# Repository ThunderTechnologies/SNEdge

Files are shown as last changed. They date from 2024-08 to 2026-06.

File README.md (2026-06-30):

# SNEdge - An Opensource SNES Edge Sharpener
**This has only been tested on a few SNES revisions | Proceed with caution**

SNEdge V2 is to a state where it can be considered stable. As SNES revisions are tested, instructions will be added to the wiki.
For now, only the full bypass is supported. The sidecar install will get a dedicated design at some point.

The SNEdge corrects much of the smearing that's present on the 2 chip SNES. It taps the console's RGB, cleanly buffers it, and applies a tuned amount of sharpening to bring back the crisp edges the stock 2 chip output loses.

This is the latest revision of the SNEdge. Over the original it refines the input biasing, properly impedance-matches the outputs to the 75Ω video standard, and re-tunes the sharpening — see [How It Works](#how-it-works) for the details. It still uses 0805 components, so it's relatively approachable to solder by hand.

The SNEdge pairs with the **Multiout QSB**, which makes for a clean install right at the multiout. There are two ways to connect the SNEdge to the QSB:

- **U.FL Coax (recommended)** — connect the two boards with U.FL-terminated 1.13mm coax (the same cable sold as WiFi antenna pigtails). This is the preferred method for new installs: it's a higher-quality, shielded connection, the U.FL connectors let you position and route the cable freely, and the cable is cheaper and easier to source than FFC. Around 10cm length works well.
- **FFC cable** — a single ribbon cable between the two boards. Still supported, but coax is the better choice going forward.

> Where to get the boards:<br />
[SNEdge V2 Gerbers](https://github.com/ThunderTechnologies/SNEdge/tree/SNEdge_V2/SNEdge%20PCB/Manufacturing)<br />
[FFC QSB Gerbers](https://github.com/ThunderTechnologies/SNEdge/tree/SNEdge_V2/Multi%20AV%20QSB/FFC%20QSB/Manufacturing)<br />
[Coax QSB Gerbers](https://github.com/ThunderTechnologies/SNEdge/tree/SNEdge_V2/Multi%20AV%20QSB/U.FL%20QSB/Manufacturing)<br />
Note:  The coax is standard U.FL 1.13mm WiFi antenna pigtail cable (roughly 10cm), widely available online.<br />

The SNEdge

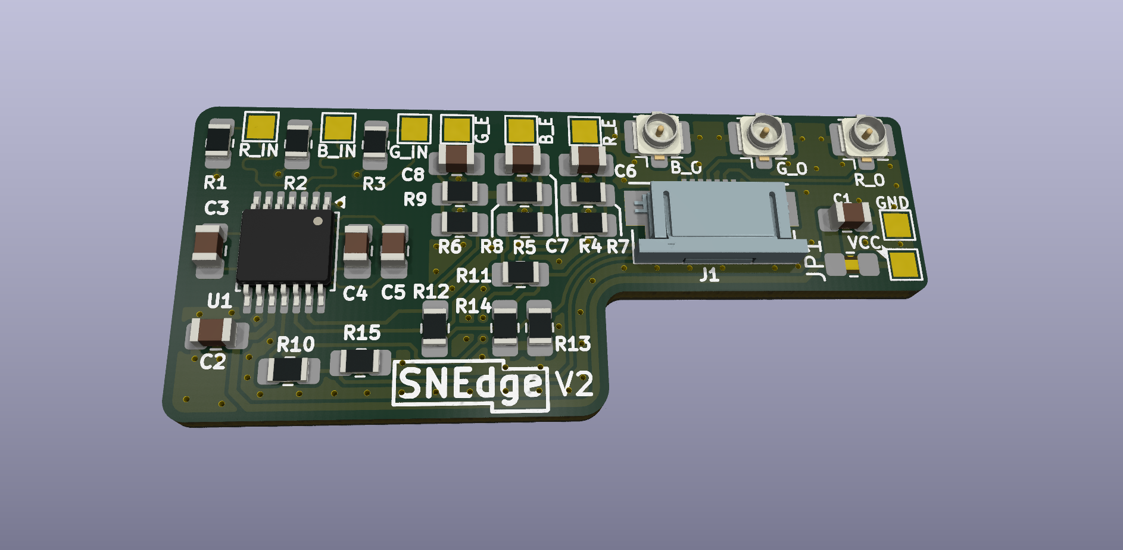
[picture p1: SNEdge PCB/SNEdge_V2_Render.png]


The Multiout U.FL QSB

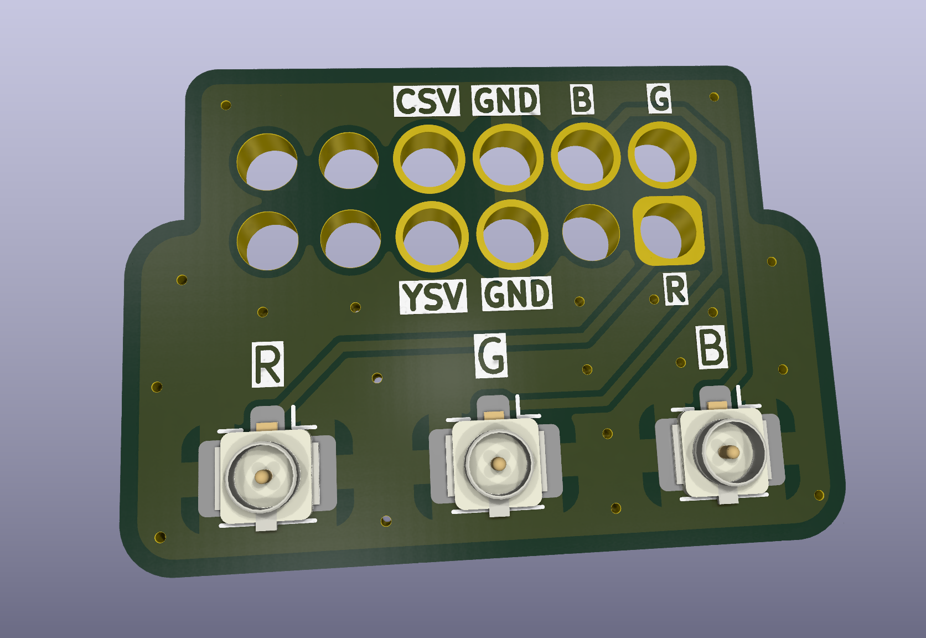
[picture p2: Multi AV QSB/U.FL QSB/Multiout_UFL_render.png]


The Multiout FFC QSB

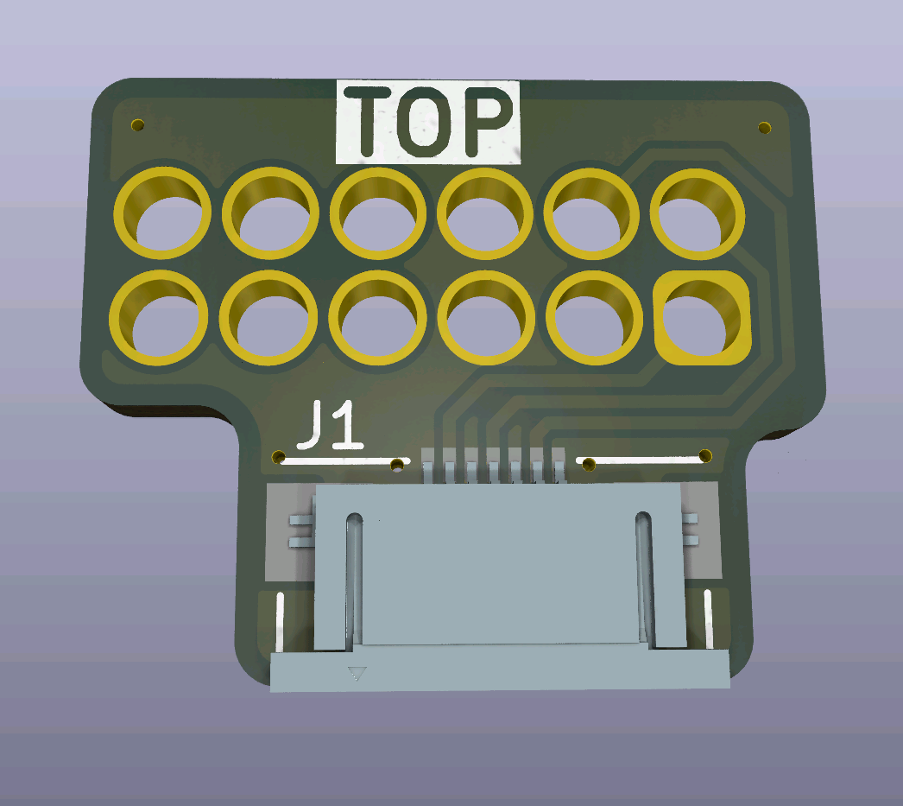
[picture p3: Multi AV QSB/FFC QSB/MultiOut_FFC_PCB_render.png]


(I'll be adding screenshots of the video output soon)

## How It Works

The SNEdge taps the RGB video signal at the PPU2 output (the Q3/Q5/Q7 points) and runs each channel through a THS7376 video amplifier. The 2 chip SNES PPU has slow color transitions that show up on screen as smearing; cleanly buffering the signal and applying a small amount of high-frequency peaking sharpens those transitions without changing the rest of the picture.

A few design choices worth knowing about:

- **Ground reference and input attenuation.** Each RGB input has a 7.5kΩ pull-down resistor. It does two jobs. First, it gives the amplifier input a proper, defined ground/DC reference so the signal sits where it should. Second, it attenuates the input down to around 2.20Vptp, which keeps the signal within the THS7376's 2.35Vptp linear input voltage spec and so avoids clipping the amplifier's input. For context, the SNES's original RGB amp has an input impedance of about 12kΩ.
- **Sharpening.** A small feedback capacitor on each channel provides the edge sharpening. It's tuned for the most sharpening you can get before overshoot starts to become visible.
- **75Ω output.** Each output uses a 240Ω / 110Ω network. The thevenin equivalent is about 75Ω, which is the standard video source impedance, so the SNEdge drives a cable correctly.
- **Optional noise caps.** Adding a 10uF cap to each of C90-C94 on the SNES motherboard helps suppress video noise. These are optional — you can leave them out and only add them if you notice any noticeable noise in the output.

## Installation
I don't have specific, picture instructions on how to install the SNEdge yet (These will be slowly added to the wiki).

However, looking at the [SNES schematic (PDF)](https://wiki.superfamicom.org/uploads/snes_schematic_color.pdf) from [wiki.superfamicom.org](wiki.superfamicom.org) will be critical for understanding how to install this.

This revision installs using the **RGB Bypass** method, which gives the best sharpness. The older **Sidecar** method (which didn't require desoldering any components) is no longer supported on this revision — see [A Note on the Sidecar Install](#a-note-on-the-sidecar-install) below if that's what you're after.

Optionally, you can solder an additional 10uF capacitor onto C90, C91, C92, C93, and C94 on the SNES motherboard (for PAL systems, it's C91, C92, C93, C94, and C95). These help reduce video noise. They aren't required, but if you notice any noticeable noise in the output, adding them should clean it up.

Below is an SOT-23 pinout I will be referencing later.
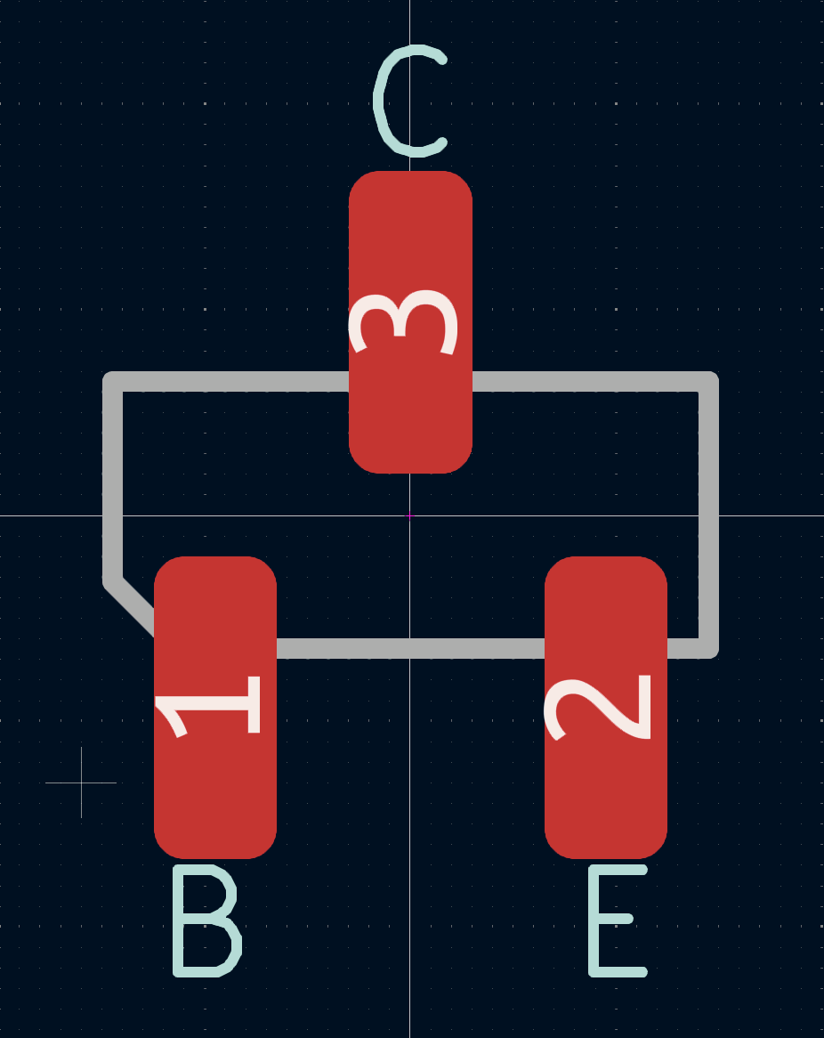
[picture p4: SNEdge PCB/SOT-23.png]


### A Note on the Sidecar Install
The Sidecar method is **not supported on this revision.** If you want a sidecar-style install, the original SNEdge can still be used for that. A dedicated sidecar revision may be released later by ThunderTechnologies.

This revision has not been tested in a sidecar configuration. It may work fine, but it's untested, so it isn't documented as a supported install here. For this revision, use the Full RGB Bypass install below.

### Full RGB Bypass Install
(Please note that PAL system installation is a bit different, I have info on this, and will be adding it eventually.)

Mount the SNEdge, keeping one priority above everything else: **keep the input wires as short as possible.**

The R, G, and B input wires are very sensitive to parasitic capacitance, so position the SNEdge so those wires reach their mainboard points (Q3, Q5, Q7) over the shortest distance you can manage. Keeping the input wires as close to the mainboard points as possible is the single most important part of placement. It's also preferred to keep the three input wires at **similar lengths** to each other.

Orientation depends on how you're connecting to the QSB:

- **Coax (recommended):** the U.FL coax gives you a lot of freedom. Orient and place the SNEdge however best keeps the input wires short, and route the coax wherever is convenient.
- **FFC:** point the FFC connector toward the multiout of the SNES.

Remove Q3, Q5, and Q7. If you only care about RGB working, remove R8, R9, R13, R14, R18, and R19. If you also care about Composite video and S-Video, also remove C6, C7, and C8.

Q3 is Red, Q5 is Green, and Q7 is Blue. Looking at the SOT-23 pinout above, pin 3 of each is ground. Pin 1 of each is the R, G, and B signals that will be soldered to the SNEdge.

Solder leads from Q3 to R_IN and GND.

Solder leads from Q5 to G_IN and GND.

Solder leads from Q7 to B_IN and GND.

The SNEdge needs to output video to U7 (S-ENC) on the SNES in order for composite video and S-video.

The SNEdge R_E, G_E, and B_E outputs go to U7's pins 20, 21, 22 respectively. (you can ignore the GND pin next to these if you'd like. If you care, connect it to pin 2 of U7.

Solder the multiout QSB on to the bottom of the SNES where the multiout pins are. If you're looking at the bottom of the SNES board, the "TOP" label on the QSB needs to be facing you. (If you're using FFC, also orient it so the FFC connector points toward the SNEdge; with coax, routing is flexible so this doesn't matter.)

The SNEdge needs 5V. Solder 5V to the + and ground to the -

Connect the SNEdge to the QSB. Coax is the recommended method:

- **Coax (recommended):** connect the SNEdge to the QSB with U.FL-terminated 1.13mm coax (the cable commonly sold as WiFi antenna pigtails). Around 10cm length works well. It's the better-quality connection, easy to route thanks to the U.FL connectors, and cheap to source.
- **FFC cable:** alternatively, connect an FFC cable between the SNEdge and the QSB. The contacts of the FFC face down, with the blue tabs facing up.

Congrats! You have completed the full RGB bypass install. Enjoy some crispy RGB.

### A Note on PAL Systems
**PAL has not been tested yet.** The SNEdge should work on PAL consoles since they share the same PPU, but please treat PAL installs as experimental for now.

The main difference to be aware of is the cap designators: if you add the optional noise-reduction caps, on PAL systems they go on **C91, C92, C93, C94, and C95** instead of C90-C94. PAL boards also differ around the encoder, so the Full RGB Bypass encoder connections (the U7 pin references above) may not match a PAL console one-to-one. Until PAL-specific details are confirmed and documented, treat a PAL install as experimental and proceed carefully. More complete PAL instructions will be added as they're verified.

### Credits

The SNEdge is based on the work of YoshiYukiBlade over on the [shmups.system11.org](https://shmups.system11.org/viewtopic.php?t=70196) forums.<br />
V2 was made possible by the many contributions from [RetroLoom](https://github.com/RetroLoom)

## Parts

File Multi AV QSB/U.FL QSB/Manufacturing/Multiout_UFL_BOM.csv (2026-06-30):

Reference | Value | Qty | Digi_PN | MFG_PN
J2 | R | 1 | H11891CT-ND | U.FL-R-SMT-1(10)
J3 | G | 1 | H11891CT-ND | U.FL-R-SMT-1(10)
J4 | B | 1 | H11891CT-ND | U.FL-R-SMT-1(10)

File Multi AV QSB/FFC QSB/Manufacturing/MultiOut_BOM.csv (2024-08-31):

Item | Qty | Reference(s) | Value | Digi_PN | MFG_PN | Type
1 | 1 | J1 | RGB_OUT | WM8933CT-ND | 527460771 | SMD

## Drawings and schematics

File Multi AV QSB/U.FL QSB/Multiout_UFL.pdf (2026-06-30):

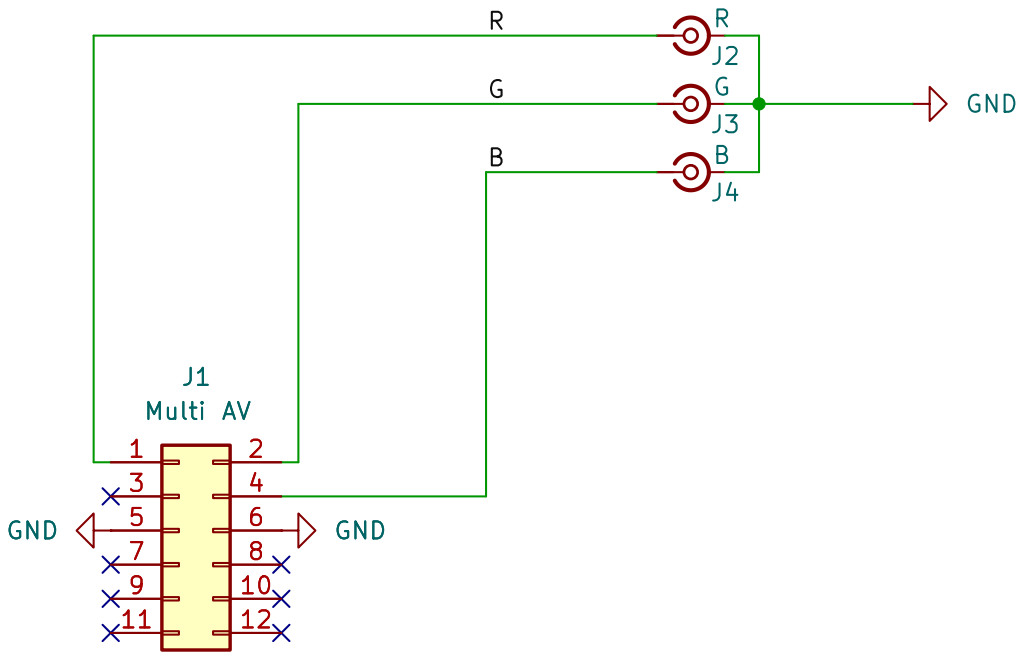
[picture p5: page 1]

Design by Daniel Arnold (RetroLoom)
Innov8bit
Sheet: /
File: Multiout_UFL.kicad_sch
Title: MultOut QSB

Size: A4 | Rev: 1
KiCad E.D.A. 10.0.3 | Id: 1/1

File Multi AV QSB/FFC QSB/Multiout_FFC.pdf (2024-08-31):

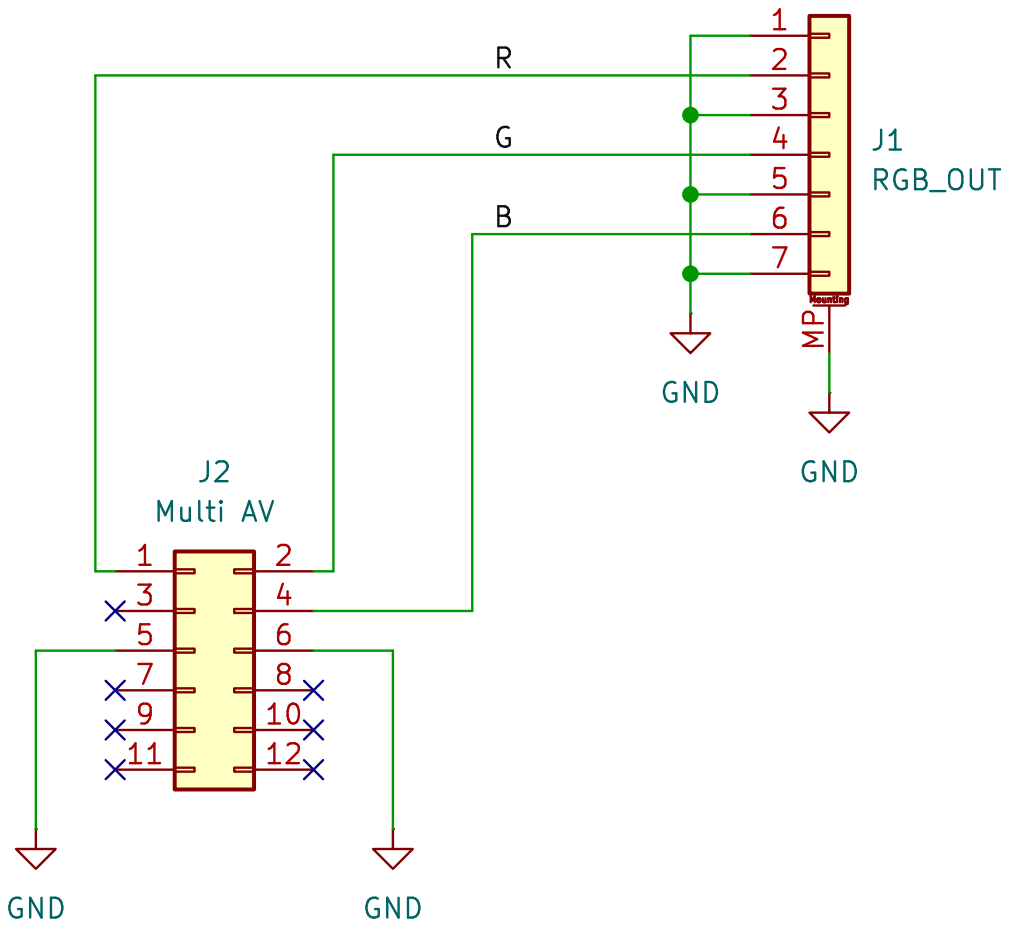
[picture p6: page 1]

File: MultiOut.kicad_sch Sheet: / ThunderTechnologies

Id: 1/1 Title: MultOut QSB

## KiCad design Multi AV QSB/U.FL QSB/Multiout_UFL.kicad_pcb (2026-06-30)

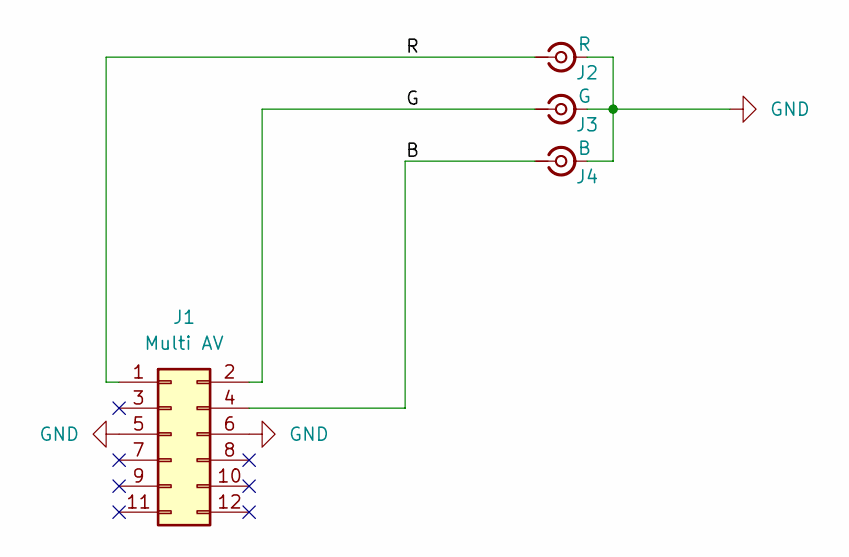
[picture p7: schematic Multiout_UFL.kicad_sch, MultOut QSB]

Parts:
J1: Multi AV; Multi_AV_QSB
J2: R; U.FL_Hirose_U.FL-R-SMT-1_Vertical; MFG_PN U.FL-R-SMT-1(10); Digi_PN H11891CT-ND
J3: G; U.FL_Hirose_U.FL-R-SMT-1_Vertical; MFG_PN U.FL-R-SMT-1(10); Digi_PN H11891CT-ND
J4: B; U.FL_Hirose_U.FL-R-SMT-1_Vertical; MFG_PN U.FL-R-SMT-1(10); Digi_PN H11891CT-ND

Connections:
/B: J1.4, J4.1 (In)
/G: J1.2, J3.1 (In)
/R: J1.1, J2.1 (In)
GND: J1.5, J1.6, J2.2 (Ext), J3.2 (Ext), J4.2 (Ext)

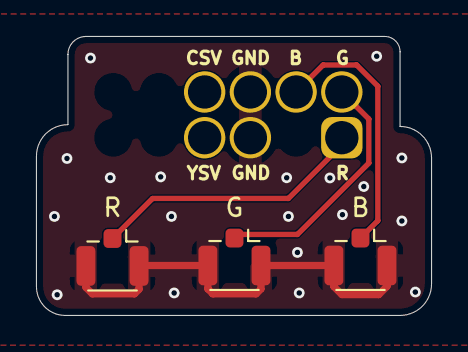
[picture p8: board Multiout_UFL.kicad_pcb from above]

Board: 2 copper layers, 21.9 x 15.5 mm, 4 parts (0 on the bottom side), 4 nets.

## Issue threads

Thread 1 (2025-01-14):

Flex Lenght

Radeon91, 2025-01-14:
hello, what distance should we use for the fex? would a 10cm be ok?

ThunderTechnologies, 2025-01-14:
10cm is what I used. Specifically, I used this part: [https://www.digikey.com/en/products/detail/molex/0150200751/2972673](https://www.digikey.com/en/products/detail/molex/0150200751/2972673)

Looks like I forgot to mention this part anywhere. I'll add this to the BOM of the SNEDGE.

Radeon91, 2025-01-15:
Great, thanks.

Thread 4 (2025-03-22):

Sidecar Install GPM-02 Vertical Bars

RetroLoom, 2025-03-22:
First I want to say thank you for your work on this implementation. Overall it was easy to install as a sidecar and I am pretty impressed with the results.

On my GPM-02 it does seem to bring out some vertical bars and a strange noise that is not present before the mod. I don't think this is unique to the SNEdge because I have seem nearly identical artifacts from using the Buttersoft / Torapu filter and its renditions on the GPM-02 as well. I spent a bit of time trying looking for ways to reduce or eliminate the lines but so far nothing has worked. I have done the usual upgrades to C90-C95 caps, and also have an upgraded voltage regulator. I tried upping C7 on the SNEdge to a 10uf which showed no change. I also tried different ground points which seemed to change / make the noise worse but I was never able to improve it. PPU2 pins 3 and 27 have been removed from the circuit by removing their series resistors which did seem to have with some of the vertical bars.

I think I am going to move on to the full bypass install and see how my results are with that, but I thought I would test and try what I could while I had it configured as a side car and report it.

RetroLoom, 2025-03-22:
I just finished the full bypass install without connecting U7 and thought I would make a quick report. 90-95% of the noise and vertical bars are no gone and everything looks very nice and stable. There is still a faint amount of vertical bars so not quite 100%. I will try to do a bit more research and attempt to get some decent captures. I will also move on to an RGB-02 revision I have at some point which didn't seem to suffer from these same artifacts when using the Buttersoft / Torapu mod after removing PPU2 pins 3 and 27 from the circuit. I will report back when I get around to this.

RetroLoom, 2025-03-22:
I repositioned the side car and shortened my wires as much as possible / practical and this seems to have eliminated all of the vertical line noise that was happening on the full bypass install. It seemed in my testing that most of this noise was caused by the extra inductance on the ground wires. I am not sure how much this would have helped with the sidecar only install because it was very prominent there. But this can be emphasized for anyone else installing this mod.

ThunderTechnologies, 2025-06-03:
Thank you for your input and testing (and my apologies for taking forever to respond). I'll be sure to mention ground wire length in the readme here soon.

leonkiriliuk, 2025-07-21:
I've been experimenting with the SNEdge on a Japanese GPM-02 and wanted to provide my feedback here. I did a full RGB bypass install with the 10uF caps added. I kept the wires as short as possible.

- SNES noise differs between SNES revisions. No single solution will fix all SNES systems. This is why other commercial products have multiple adapters, depending on what system you have.
- If your display device is a CRT (composite, SVideo) or RGB CRT (PVM) then the solution is pretty much perfect. I can't tell the difference between a SNEdge modded system and my 1chip on my PVM! Before I easily could. The SNEdge gets rid of the horizontal smear that the SNES suffers from.
- If your display device is an LCD, you're at the mercy of your scalar and more work is needed to get it to 1chip quality on some SNES systems.
- Some SNES systems (like the GPM-02) have high frequency noise in the video signal. The original RGB path did a good job at hiding this noise by smearing it away. When you get rid of the smear, your scalar does a good job at making the existing noise visible.
- Other solutions show the vertical jailbars as well. Voultar's wiki shows it in his screen captures of the GPM-02 basic install. RetroSix talks about it in his Wiki (he believes it to be DRAM noise)
- Some of the solutions discussed here (like adding 15pF caps on the input) remove some of this noise by simply introducing some of the smear back. They don't tackle the original source of the noise. I played with different values for these caps; the higher the value, the higher the horizontal smear comes back.
- OSSC Pro in scalar mode, with the built-in SNES profile, does the exact same thing. It removes the vertical jailbars by introducing a small amount of horizontal smear. In pure or adaptive line multiplier, the vertical bars are perfectly visible, but the image is also perfectly sharp.
- Swapping a THS7374 for the THS7376 showed no difference. I believe you can use both.
- Enabling the built-in filter of the TI video amps turns on their internal input filters which generates a lot of smear. I'm guessing it's equivalent to adding 100pF caps on the input.

On the GPM-02 I've done other experiments:
- adding SVideo / component output with the full RGB bypass doesn't impact RGB output image quality
- the 3 ground wires for RGB inputs don't make a difference if they're there or not
- lifting the S-PPU2 RGB pins (95,96,97) and running dedicated wires directly to the SNEdge made no difference

leonkiriliuk, 2025-07-21:
SNES is noisy by nature (Even 1chip) Turn off LPF on an SNES 1CHIP RGB amp, feed it into OSSC and you'll see the noise in solid black screen.  The THS7374 LPF does a good job at removing it. The GSCARTSW uses the same chip and has it on by default which is why people turn off the LPF on the RGB amp (too many LPFs tend to blur the image a bit)

The SNEdge output has no LPF at all (pin 9 is held at Vcc = LPF off) So now you let all the noise through while trying to remove it.

As for ground; if you look at the PCB, you'll see all the grounds connect to the same ground plain. There's such a thing as too many grounds; N64 suffers from this - too many grounds can introduce ground loops / noise.

I'll try and get other SNES models and play around. I think the design GPM-02 has inherit high frequency noise in the video output. It needs to be identified and removed. I hope other revisions have less.

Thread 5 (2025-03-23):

RGB Pins Shorted to Ground?

SnoopKatt, 2025-03-23:
I did the install and am running into something odd. I did the full bypass and followed the steps to enable S-video and composite. When I tried RGB with two different cables I get no video (but I get audio). Composite video works. RGB used to work fine on this SNES.

I see all the pins on the flex are shorted to ground on the main board (the board with the THS7376), even when it is uninstalled from the SNES. Given that composite video works, it seems like the soldering should be ok. Any ideas? Thanks.

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

RetroLoom, 2025-03-23:
If you purchased this kit from a seller on eBay, this might be related to issues posted by this user on reddit https://www.reddit.com/r/snes/comments/1j2lyrx/snedge_installed_results_not_quite_how_i_expected/

Apparently there was a bad batch of these sold that had grounding issues like you mentioned. Maybe your source is different, but I thought it might be useful to mention.

I built my SNEdge kit from scratch and had no issues like this.

SnoopKatt, 2025-03-23:
Thanks. This actually tracks. I bought it directly from the seller's website (PCP Retrotech), but probably the same source. Bummer... I'll take a closer look to see if I can etch off the ground connections

Closed 2025-03-23.

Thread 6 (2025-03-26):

Revision RGB-01 Incompatibility

RetroLoom, 2025-03-26:
I decided to attempt the full RGB bypass install on my RGB-01 last night which sent me on a rabbit hole spending hours trying to debug through this morning. I knew this revision of the board had a different circuit, but I was surprised to find out just how different this circuit is from the schematic. I removed all expected sets of resistors and capacitors that would normally be related to taking the encoder out of the circuit but when everything was connected I was getting a very strange interference that would fade the picture to black vertically from left to right. I went through the entire process of checking for any shorts or bad solder joints and had even thought at one point that the THS7376 was defective so I swapped it out. Nothing seemed to help or change and this was present on all colors. Eventually I decided to revert everything back to stock to double check that something hadn't been damaged outside of the SNEdge mod. In the process of putting things back together I may have discovered what might be going on.

Here are some before and after photos of my configuration before installing.

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 - Stock config without transistors

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 - Reconfigured resistors

I usually try to keep all of the resistors around so it is easy to reverse later if I need to, but I double checked to make sure none of the resistors soldered on the side were in contact with any other solder points. Everything was good.

However, when I went through the process of reverting things to stock I decided to restore just the resistors so they would have proper biasing for the resistors but I had decided to leave C6 C7 and C8 out of the circuit so that the encoder would stay disconnected out of the circuit. Based off of the schematic this should have kept the restored the direct RGB output from the multi AV output but to my surprise the RGB out was not working. I had to add C6 C7 and C8 back into the circuit for the RGB lines of the multi out to work. I determined that in the RGB-01 the RGB lines connect after C6 C7 and C8 and the lines connect parallel between the multi out and encoder. This would make sense to the interference I was having because it would mean that the encoder was directly interfering with the multi out.

I may attempt to forgo the connection to the QSB and tap the encoder outputs of the SNEdge directly to C6 C7 C8 connecting to the encoder and multi AV to see if this is a proper solution. However, I feel like there might need to be some adjustments to the resistor network for this to work at proper resistance and termination. For the moment I thought it would be good to bring some awareness to this.

RetroLoom, 2025-03-26:
I decided to do a quick wiring up to test my proposed solution and so far it seems to work well. So my recommendation for a RGB revision install is to remove the transistors as well as C6 C7 and C8. Then connect the SNEdge encoder outputs to C6 C7 C8 on the sides that connect to the encoder. The QSB does not seem to be compatible with this revision without maybe removing or cutting traces from the encoder lines to the multi out. This is unfortunate since the QSB would give a more isolated and direct path, but so far the image quality looks very good this way. I have not checked peak to peak voltage to verify whether the resistor network needs adjustment, but nothing seems too far out of spec at a glance.

Here is a photo of the working config.
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

AlSiSan, 2025-06-02:
I did it on mine, with good results. Just minor noise.  I had those resistors removed if I remember well. I was inspecting traces with the multimeter but didn't take note of them. And disabled CV and S-Video.

moncat2005, 2025-07-06:
I tried installing the Snedge board and used braided shielded wires (1.13mm and 1.3mm) for both input and output signal cables.
The RGB return signal line after Snedge buffer processing is a 4-core shielded wire, and only one side is grounded on the Snedge board, which may not be a good idea to pay attention to.
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

After the renovation was completed, there was a significant improvement in the overall image edge ghosting.
When the scanning line mode is enabled in GBS-C, it is almost impossible to detect edge ghosting issues, but there are visible periodic vertical bars horizontally (the photo is too bad).
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

However, in the 480i display mode on the test screen, there are still some ringing like marks on the edges.
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

I don't know if this problem is caused by the downstream encoding circuit or by my improper handling.
I haven't had the chance to implement the complete bypass QSB output transformation plan yet.

RetroLoom, 2025-07-13:
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

Thanks for the information. Using the shielded two-pole wiring is a good idea.

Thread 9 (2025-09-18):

Black screen sd2snes

Neorad1870, 2025-09-18:
Hello, I have a Japanese SNES reference: GPM 02 with switchless dezoning, before the RGB mod the SD2SNES worked but since then I have a black screen but all the other games work perfectly, I specify that the SD2SNES works on another console, do you think it is a power supply problem? voltage regulator? the assembly is complete , thank

RetroLoom, 2025-09-18:
This isn't something I have experienced yet from a SNEdge install and I haven't heard of this happening to anyone else. Suspecting something like the voltage regulator or something with the power is very possible, but it would be hard to know without some testing. I don't think an upgraded voltage regulator would be necessary for this, but a faulty regulator might cause something like this. If you have a multimeter you could start with measuring the voltage coming from the regulator and see if anything looks abnormal. That being said, all of my SNES use a LM78S05 or other upgraded regulator so I may not have noticed any issues that might be present on a regular LM7805.

Neorad1870, 2025-09-18:
Hi, thanks for your reply. I changed the regulator in the meantime and the problem is solved. This time everything works perfectly.

https://youtube.com/shorts/2ecK3ADk5Gk?si=SpoMwwHKP7URN0gq

RetroLoom, 2025-09-18:
Cool, it looks good! Glad that it worked!

Neorad1870, 2025-09-18:
a little comment and a thumbs up on the video would be cool 😆

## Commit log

2024-08-19 Initial Design
    [SNEdge.kicad_pcb, SNEdge.kicad_sch]
2024-08-19 Rearrange folders
    [SNEdge.kicad_pcb, SNEdge.kicad_sch]
2024-08-19 Created MultiOut QSB
    [MultiOut.kicad_pcb, MultiOut.kicad_sch]
2024-08-19 Added BOM
    [SNEdge.csv]
2024-08-19 Added Schematics
2024-08-31 Prepping for release
    [MultiOut-B_Cu.gbr, MultiOut-B_Mask.gbr, MultiOut-B_Paste.gbr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]
2024-10-05 getting ready for alpha release
    [MultiOut.kicad_pcb, SNEdge.kicad_pcb]
2024-11-26 Added SOT-23
    [MultiOut-B_Cu.gbr, MultiOut-B_Mask.gbr, MultiOut-B_Paste.gbr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]
2025-01-14 Update SNEdge_BOM.csv
    Added FFC cable PN
    [SNEdge_BOM.csv]
2025-01-14 Update SNEdge_BOM.csv
    Forgot a field
    [SNEdge_BOM.csv]
2025-09-06 AC coupled input, SD filter enabled
    [SNEdge.kicad_pcb, SNEdge.kicad_sch]
2025-09-08 SNEdge 2 with component switch
    [SNEdge.kicad_pcb, SNEdge.kicad_sch]
2025-11-10 Cleaned up component side
    [SNEdge.kicad_pcb, SNEdge.kicad_sch]
2025-11-11 Added voltage dividers on RGB input
    [SNEdge.kicad_pcb, SNEdge.kicad_sch]
2025-12-10 Remove component inputs and switch, refine SNEdge
    [SNEdge.kicad_pcb, SNEdge.kicad_sch]
2025-12-10 Change directory name to indicate SNEdge Revision 2
    [SNEdge.csv, SNEdge.kicad_pcb, SNEdge.kicad_sch]
2025-12-11 Reverse RGB output to match QSB
    [SNEdge.kicad_pcb]
2025-12-11 Add more ground plane stitching
    [SNEdge.kicad_pcb]
2025-12-12 Multi AV QSB - Coax and Coupling Capacitors
    [MultiOut.kicad_pcb, MultiOut.kicad_sch]
2026-01-07 v2.1 remove voltage divider and voltage regulator, input pull down and power filtering
    [SNEdge.kicad_pcb, SNEdge.kicad_sch]
2026-01-10 Refactor for purity
    [SNEdge.kicad_pcb, SNEdge.kicad_sch]
2026-01-10 Add encoder coupling capacitors back
    [SNEdge.kicad_pcb, SNEdge.kicad_sch]
2026-01-10 Add ground stitching
    [SNEdge.kicad_pcb]
2026-01-10 Switch position of ferrite bead and bulk capacitor
    [SNEdge.kicad_pcb, SNEdge.kicad_sch]
2026-01-10 Fix input trace length
    [SNEdge.kicad_pcb]
2026-01-10 Small update to PCB
    [SNEdge.kicad_pcb]
2026-01-10 QSB - remove AC coupling and add GND lift jumper
    [MultiOut.kicad_pcb, MultiOut.kicad_sch]
2026-01-10 Small SNEdge update for THS VCC decoupling cap
    [SNEdge.kicad_pcb]
2026-02-12 Update references and a bit of clean up
    [SNEdge.kicad_pcb, SNEdge.kicad_sch]
2026-03-06 V2 based on RetroLoom's Rev2
    [SNEdge-B_Cu.gbr, SNEdge-B_Mask.gbr, SNEdge-B_Paste.gbr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]
2026-04-30 Update coax QSB for new RGB order layout
    [MultiOut.kicad_pcb, MultiOut.kicad_sch]
2026-05-04 Adjust feedback capacitors to 10pF
    [SNEdge.kicad_pcb, SNEdge.kicad_sch]
2026-06-07 Updating the branch to include all stuff from collab
    [MultiOut-B_Cu.gbr, MultiOut-B_Mask.gbr, MultiOut-B_Paste.gbr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]
2026-06-28 Remove redundant rev2 and coax folders
    [MultiOut.kicad_pcb, MultiOut.kicad_sch, SNEdge.csv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]
2026-06-28 README remove multi ground input source reference
2026-06-28 Reference input attenuation with 7.5k pull down resistors
2026-06-29 added ohm symbols when talking about resistance added reference to thevenin added some context to original input impedance added links to gerbers removed reference to being an alpha release added cre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
2026-07-09 added dedicated sidcar version (still need to make gerbers)
    [Multiout_UFL.kicad_pcb, Multiout_UFL.kicad_sch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]
